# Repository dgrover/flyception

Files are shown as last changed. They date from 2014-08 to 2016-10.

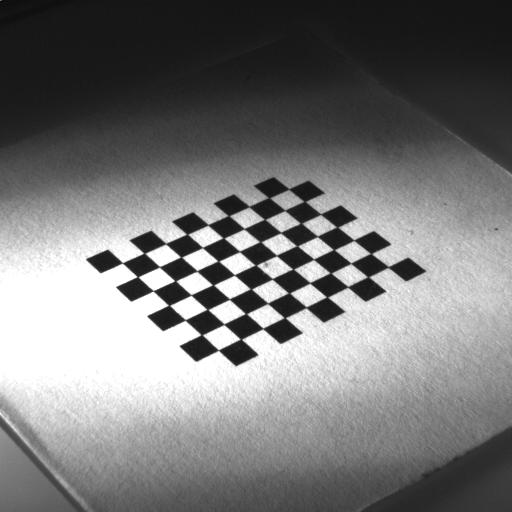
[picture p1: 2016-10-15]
calibration/arena/cbview_09192016.jpg

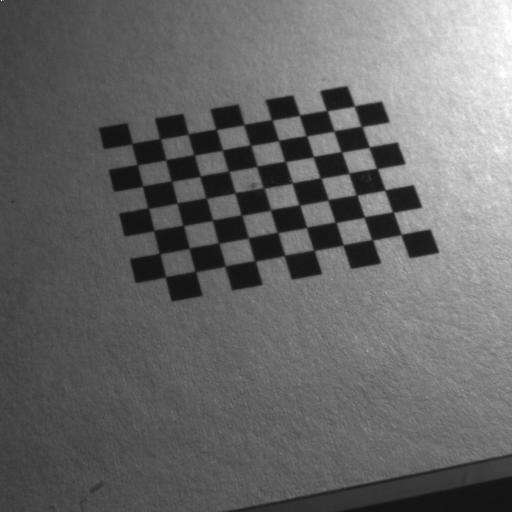
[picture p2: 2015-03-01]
calibration/arena/cbview_06192015.jpg

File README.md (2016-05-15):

# flyception

Flyception is a tracking and imaging system that enables the monitoring of brain activity in freely walking fruit flies, making the analysis of calcium dynamics possible in studies of neural mechanisms such as those that underlie social behaviors.

Please cite the following publication when used - 

Grover D, Katsuki T, Greenspan RJ. Flyception: imaging brain activity in freely walking fruit flies. Nat. Methods doi:10.1038/NMETH.3866 (2016)

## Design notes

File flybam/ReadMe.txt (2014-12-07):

========================================================================
    CONSOLE APPLICATION : flybam Project Overview
========================================================================

AppWizard has created this flybam application for you.

This file contains a summary of what you will find in each of the files that
make up your flybam application.

flybam.vcxproj
    This is the main project file for VC++ projects generated using an Application Wizard.
    It contains information about the version of Visual C++ that generated the file, and
    information about the platforms, configurations, and project features selected with the
    Application Wizard.

flybam.vcxproj.filters
    This is the filters file for VC++ projects generated using an Application Wizard. 
    It contains information about the association between the files in your project 
    and the filters. This association is used in the IDE to show grouping of files with
    similar extensions under a specific node (for e.g. ".cpp" files are associated with the
    "Source Files" filter).

flybam.cpp
    This is the main application source file.

/////////////////////////////////////////////////////////////////////////////
Other standard files:

StdAfx.h, StdAfx.cpp
    These files are used to build a precompiled header (PCH) file
    named flybam.pch and a precompiled types file named StdAfx.obj.

/////////////////////////////////////////////////////////////////////////////
Other notes:

AppWizard uses "TODO:" comments to indicate parts of the source code you
should add to or customize.

/////////////////////////////////////////////////////////////////////////////

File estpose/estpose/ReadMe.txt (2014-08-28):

========================================================================
    CONSOLE APPLICATION : estpose Project Overview
========================================================================

AppWizard has created this estpose application for you.

This file contains a summary of what you will find in each of the files that
make up your estpose application.

estpose.vcxproj
    This is the main project file for VC++ projects generated using an Application Wizard.
    It contains information about the version of Visual C++ that generated the file, and
    information about the platforms, configurations, and project features selected with the
    Application Wizard.

estpose.vcxproj.filters
    This is the filters file for VC++ projects generated using an Application Wizard. 
    It contains information about the association between the files in your project 
    and the filters. This association is used in the IDE to show grouping of files with
    similar extensions under a specific node (for e.g. ".cpp" files are associated with the
    "Source Files" filter).

estpose.cpp
    This is the main application source file.

/////////////////////////////////////////////////////////////////////////////
Other standard files:

StdAfx.h, StdAfx.cpp
    These files are used to build a precompiled header (PCH) file
    named estpose.pch and a precompiled types file named StdAfx.obj.

/////////////////////////////////////////////////////////////////////////////
Other notes:

AppWizard uses "TODO:" comments to indicate parts of the source code you
should add to or customize.

/////////////////////////////////////////////////////////////////////////////

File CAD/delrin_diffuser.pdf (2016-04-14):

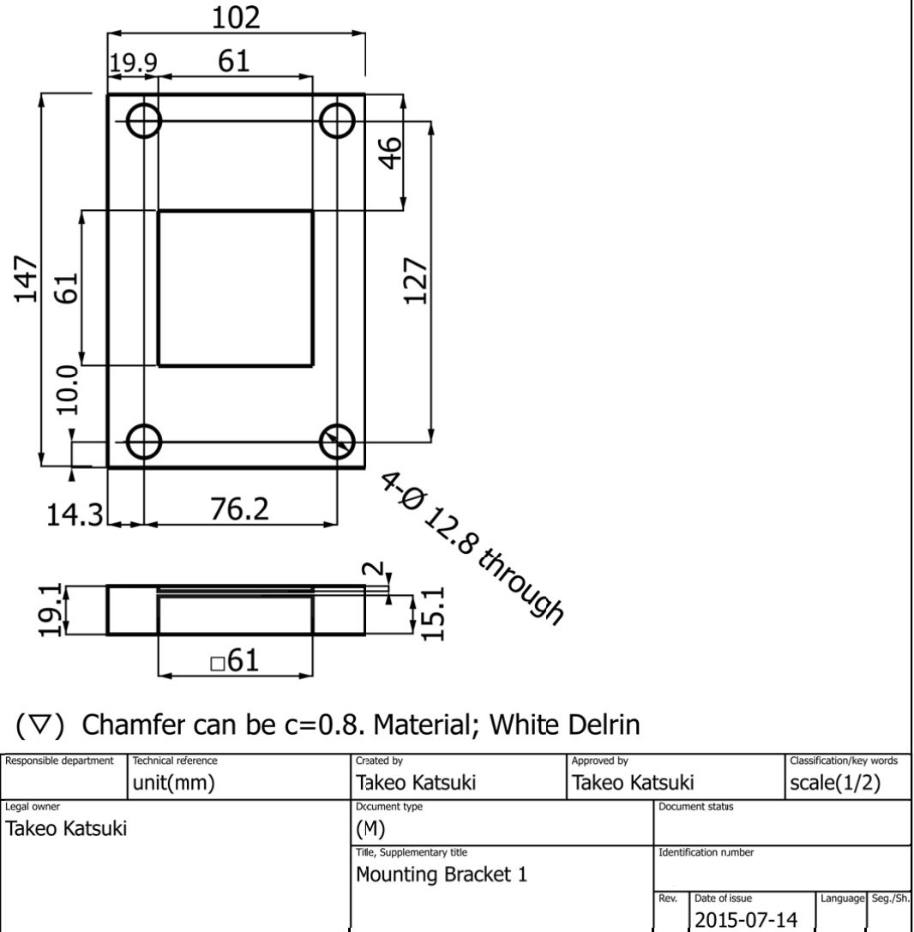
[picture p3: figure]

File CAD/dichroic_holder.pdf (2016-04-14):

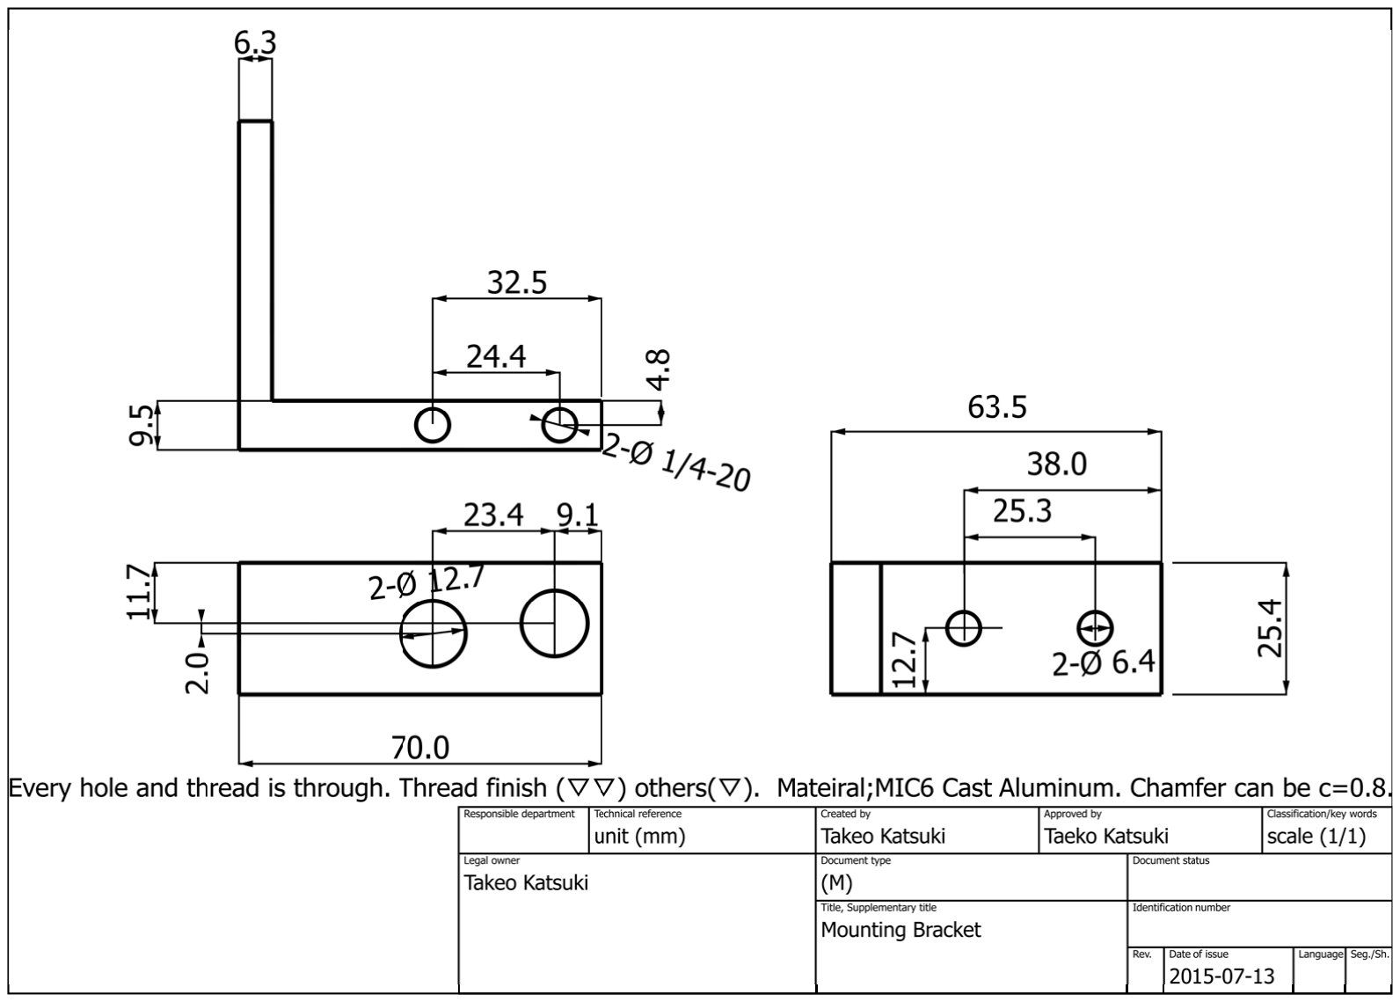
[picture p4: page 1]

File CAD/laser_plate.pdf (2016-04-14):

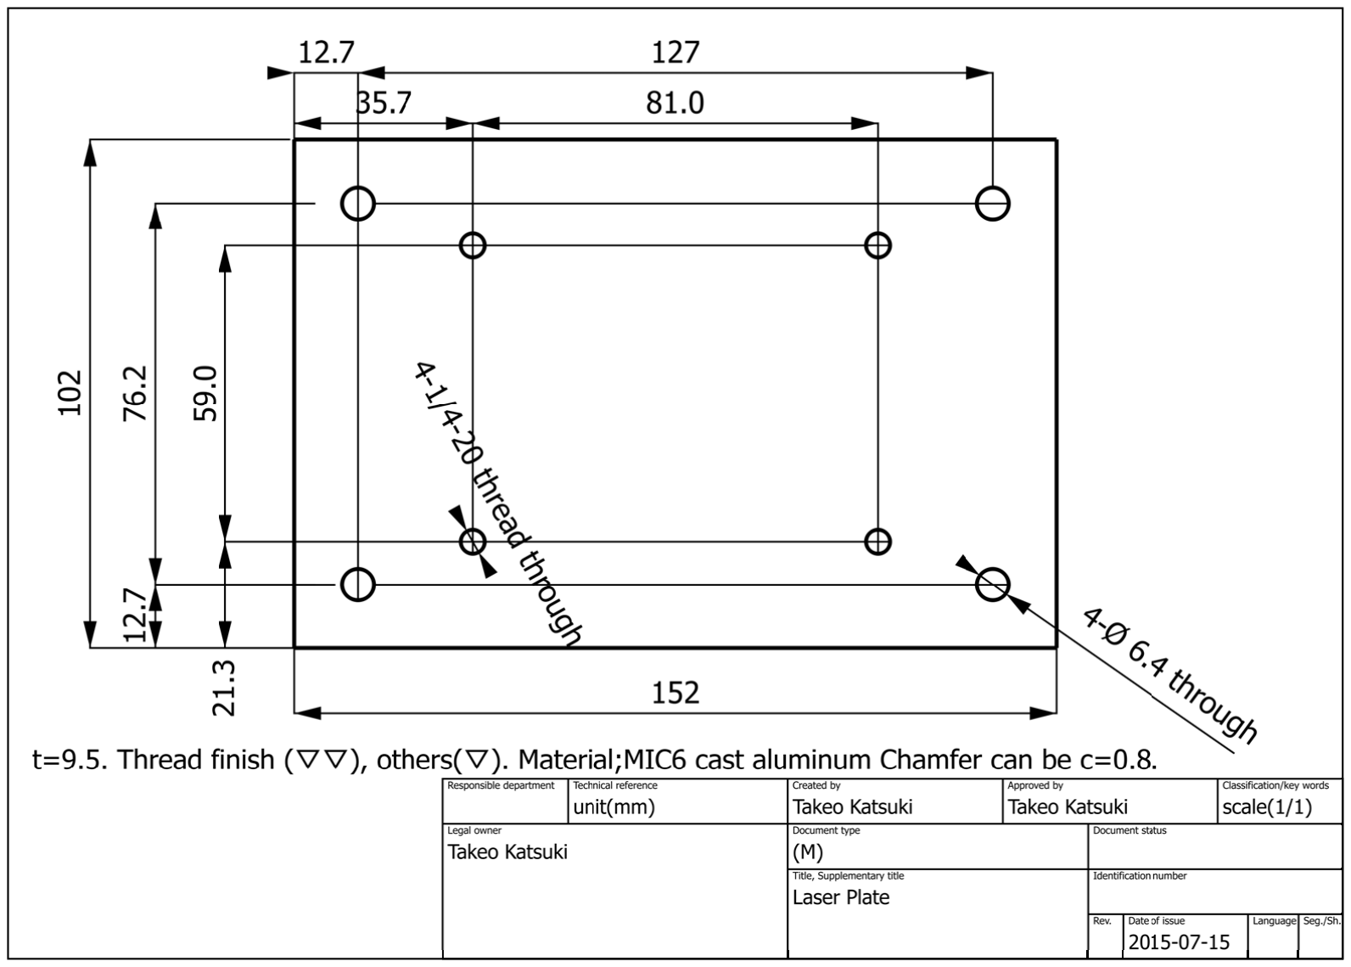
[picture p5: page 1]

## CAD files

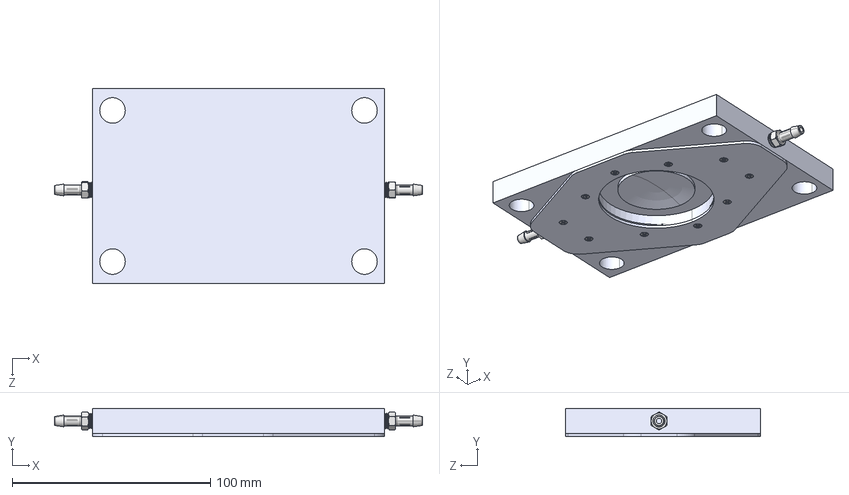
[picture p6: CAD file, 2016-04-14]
CAD/arena_fixture.STEP
185.5 x 14.3 x 98.4 mm
takeo''s fixture base
takeo''s fixture top
flat head screw_ai_CR-FHMS 0.086-64x0.3125x0.3125-N x 10
5047K114 fitting_5047K114 x 2

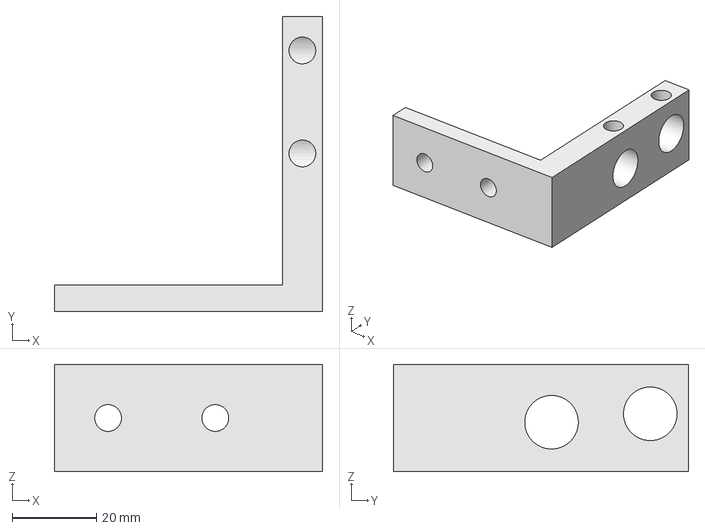
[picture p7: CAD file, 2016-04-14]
CAD/dichroic_holder.step
63.5 x 70.0 x 25.4 mm

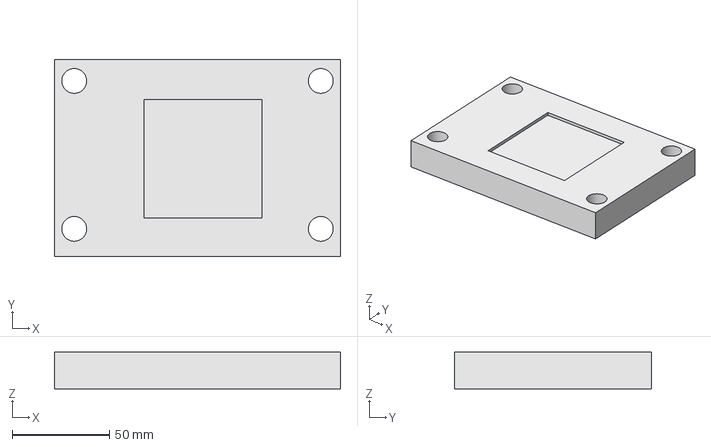
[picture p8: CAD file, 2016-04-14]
CAD/delrin_diffuser.step
147.3 x 101.6 x 19.1 mm

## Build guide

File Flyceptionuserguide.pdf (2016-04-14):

# Flyception user manual

### Dhruv Grover, Takeo Katsuki, and Ralph J. Greenspan

Version 1.0
2016-4-13

# Table of contents

Installation
Prerequisites
Hardware configuration on test setup Getting Started
Compiling
Custom building OpenCV with CMake
Compiling custom OpenCV source in Visual Studio Setting up Flyception
Compiling Flyception
Arenaview Camera Calibration
Using Flyception
Fluorescence video recording with MicroManager Postacquisition Image analysis on R

# Installation

## Prerequisites

PC running Microsoft Windows 7/8 64-bit Microsoft Visual Studio 2013 Professional Edition CMake
OpenCV library
Point Grey Flycapture SDK 64-bit
Teledyne DALSA Sapera LT SDK NI-DAQmx
Arduino
MicroManager

## Hardware configuration on test setup

Dell Precision T7610 Workstation (Sixcore 2.6GHz)
16GB RAM
2x256GB SSD drives, one for Windows OS and second for video recording Teledyne DALSA XCelera PX4 full framegrabber PCIE card

National Instruments PCIE-6351 DAQ Point Grey 2-port USB3 PCIE card Firewire 800 card
Arduino Mega 2560

## Getting Started

Download and install Microsoft Visual Studio 2013. For academic use, free licensed copies of the software are available on dreamspark.com

Download and install CMake v3.3 or above (https://cmake.org/).

Download OpenCV source code (v3.0 or above required) from GitHub (https://github.com/Itseez/opencv). OpenCV for windows provided on opencv.org can also be downloaded as it includes the source code along with a default build, however, the flyception software requires a custom build of OpenCV.

Download and install the latest version of Point Grey Flycapture SDK 64-bit (v2.8 or above) from (https://www.ptgrey.com/support/downloads).

Download and install the latest version of National Instruments DAQmx software from (http://sine.ni.com/nips/cds/view/p/lang/en/nid/10181).

Download and install the Sapera LT SDK from Teledyne DALSA (https://www.teledynedalsa.com/imaging/products/software/sapera/lt/). An account creation step might be required for software download. This software is included with the framegrabber card.

Download and install the latest Arduino IDE environment from (https://www.arduino.cc/en/Main/Software).

Download and install the latest version of MicroManager (https://www.micromanager.org/). (https://www.micro-manager.org/)

# Compiling

## Custom building OpenCV with CMake

The following instructions are similar to those provided by OpenCV at (http://docs.opencv.org/3.0-beta/doc/tutorials/introduction/windows_install/windows_install.html)

Unzip the OpenCV source code to C:\SDK\opencv-3.0.0\sources\ folder
Create a folder C:\SDK\opencv-3.0.0\build\ to hold the custom built binaries
Run the cmakegui program
Enter the full paths for the OpenCV source code and binaries
Select the grouped and advanced options and press configure
Select Visual Studio 12.0 (2013) Win64 as the compiler of choice Uncheck BUILD->DOCS
Check WITH->WITH_OPENMP
Press configure again and verify that OpenMP module has been loaded
Press configure again to include OpenMP and then press generate

The source code for the OpenCV library with OpenMP support for Visual Studio 2013 will now be saved to the binaries folder indicated in CMake.

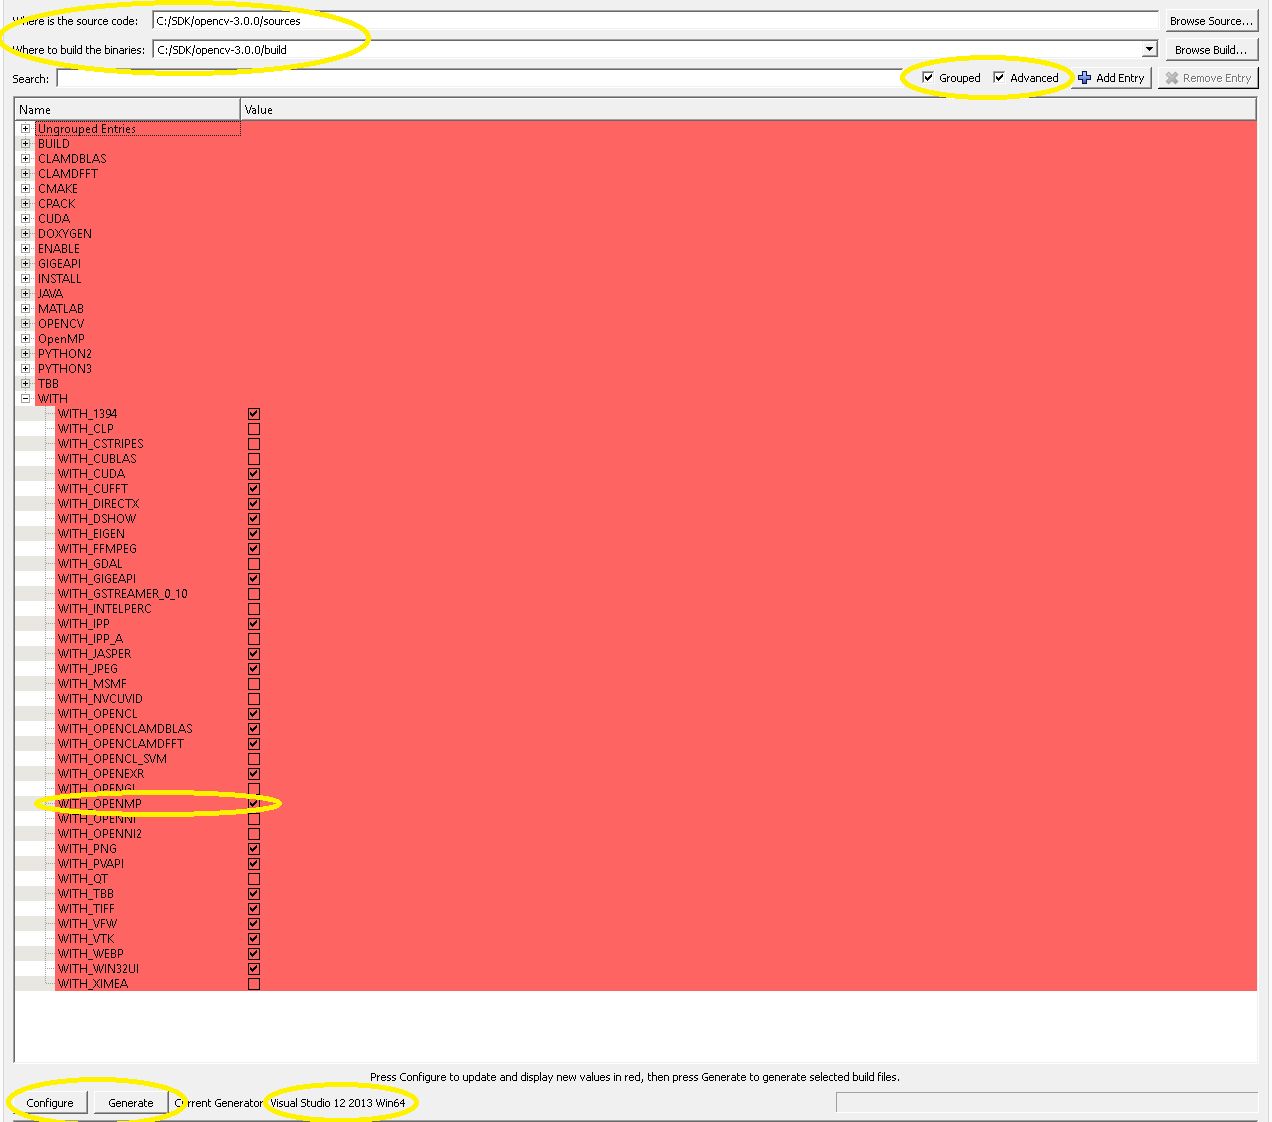
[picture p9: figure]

## Compiling custom OpenCV source in Visual Studio

Navigate to C:\SDK\opencv-3.0.0\build and run the OpenCV.sln visual studio solution file

Once loaded, select the ALL_BUILD project and use the RELEASE solution configuration, and x64 solution platform. Select the BUILD menu item and then build ALL_BUILD

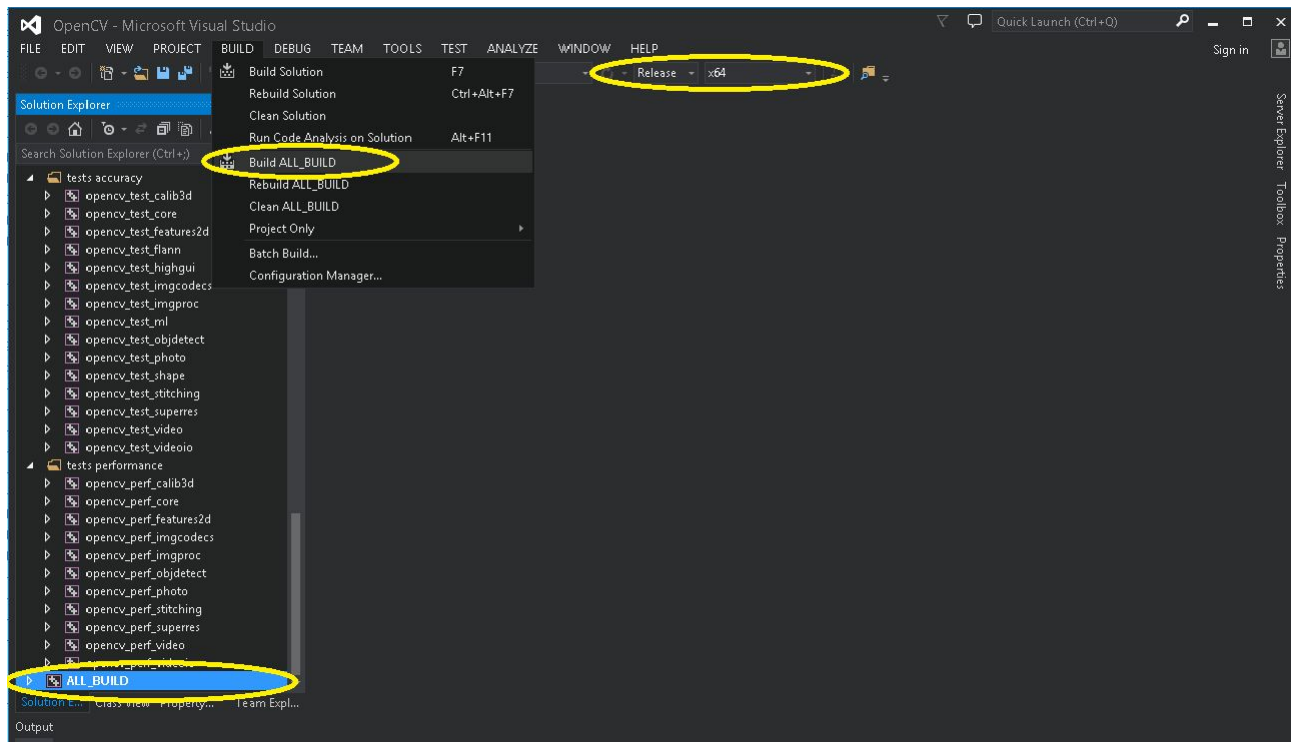
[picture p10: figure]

OpenCV should now begin compiling. This process may take a few minutes.

Once compiled, select the INSTALL project and then the BUILD menu item followed by build INSTALL. This installs the OpenCV binaries built to the folder C:\SDK\opencv-3.0.0\build\install\

Custom binaries of OpenCV with OpenMP support are now built and are saved to the following folders. In the next section, we will be including these folder paths when compiling the flyception source code

INCLUDE PATH C:\SDK\opencv-3.0.0\build\install\include
LIB PATH C:\SDK\opencv-3.0.0\build\install\x64\vc12\lib
BIN PATH C:\SDK\opencv-3.0.0\build\install\x64\vc12\bin

Note: Path to the OpenCV bin folder needs to be included in the SYSTEM Path. This can be achieved by navigating to Control Panel > System > Advanced System Settings > Environment Variables > System Variables > Path. Add the aforementioned BIN PATH to the path string. A restart of Windows may be required for the system path to be refreshed.

## Setting up Flyception

Download the latest version of the flyception source code from https://github.com/dgrover/flyception.

The flyception source code has the following folder hierarchy:
Flyception root folder
Flyception\Arduino includes code to be installed on the arduino for camera triggering and odor delivery
Flyception\flybam source code for the tracking program
Flyception\calibration scripts to calibrate the arenaview camera to convert pixel coordinates to realworld coordinates
Flyception\ccf camera link configuration file for Point Grey Gazelle camera (flyview)

Compile and upload the arduino sketch multi_cam_trigger_mega to the first arduino. This generates PWM signals to trigger the arenaview, flyview, fluoview cameras and the flash using synchronized arduino timers.

## Compiling Flyception

Navigate to the Flyception\flybam folder and run the flybam.sln solution file.
Verify that the x64\RELEASE solution platform is selected.

The provided project file includes the path to all prerequisite libraries, however, if custom folders were used, the library paths need to be changed here.

Navigate to Project > flybam properties > configuration properties > vc++ directories
Verify the following directories are included

Include directories
C:\Program Files\Point Grey Research\FlyCapture2\include C:\SDK\opencv-3.0.0\build\install\include
C:\Program Files x86\National Instruments\Shared\ExternalCompilerSupport\C\include C:\Program Files\Teledyne DALSA\Sapera\Examples\Classes\Common
C:\Program Files\Teledyne DALSA\Sapera\Classes\Basic
C:\Program Files\Teledyne DALSA\Sapera\Include

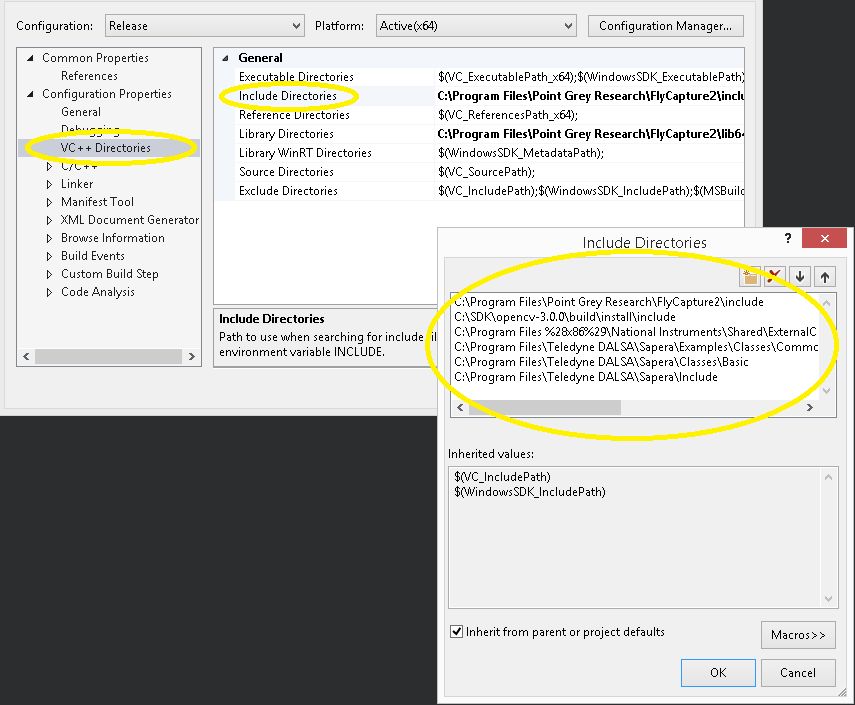
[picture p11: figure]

Library directories
C:\Program Files\Point Grey Research\FlyCapture2\lib64 C:\SDK\opencv-3.0.0\build\install\x64\vc12\lib
C:\Program Files %28x86%29\National Instruments\Shared\ExternalCompilerSupport\C\lib64\msvc C:\Program Files\Teledyne DALSA\Sapera\Lib\Win64
Under Linker > Input, verify the following .lib files are included

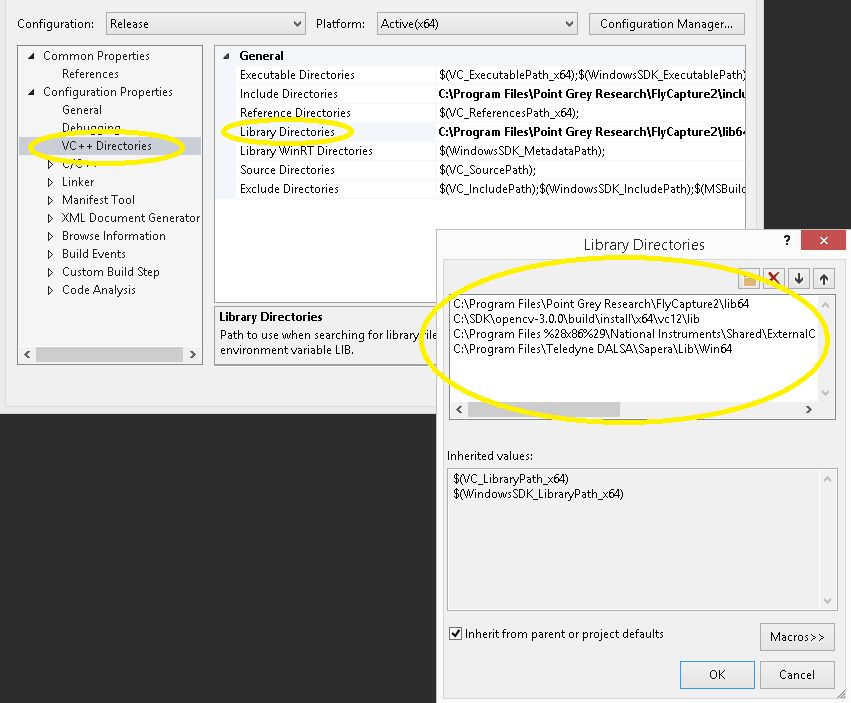
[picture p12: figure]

nid

a

q

m

x.lib
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
2.lib
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
UI.lib
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
0.lib
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
0.lib
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
0.lib
o

p

e

n

c

v_im

g

p

r

o

c

3

0

0.lib
o

p

e

n

c

v_im

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
0.lib
o

p

e

n

c

v_

c

alib

3

d

3

0

0.lib
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
sic.lib

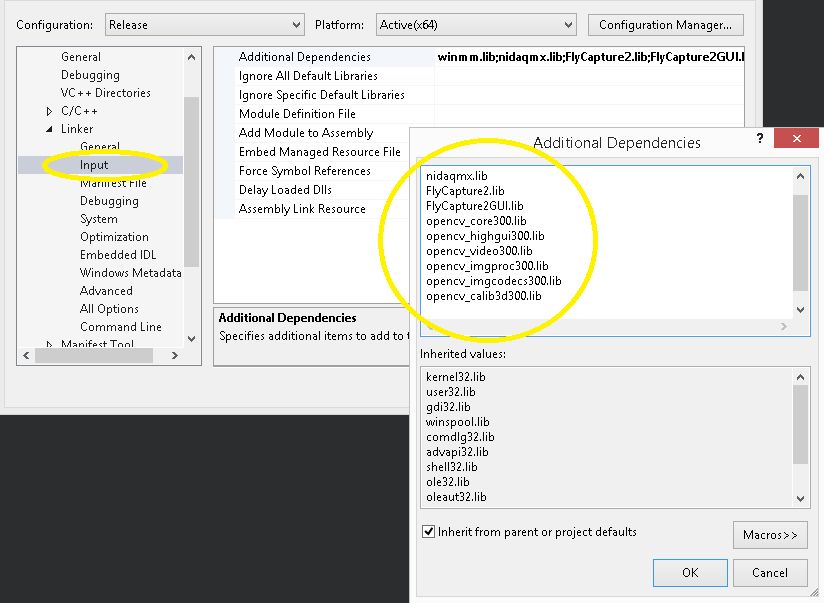
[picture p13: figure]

With these folder paths included, the flyception software is ready to be compiled and executed.

# Arenaview Camera Calibration

We follow a similar procedure to the OpenCV tutorial on camera calibration. In short, the distortion and camera matrices are calculated from arenaview input images of a checkerboard target at different orientations (roughly 8-10 images are sufficient for accurate calibration, see calibration\arena\images folder for samples). The calibration\arena\images subfolder includes images taken during a successful calibration.

See the following link for a tutorial with detailed description on the theory and use of the camera calibration routines.
(http://docs.opencv.org/3.0-beta/doc/tutorials/calib3d/camera_calibration/camera_calibration.ht ml) (http://docs.opencv.org/3.0-beta/doc/tutorials/calib3d/camera_calibration/camera_calibration.html)

The calibration\calib folder includes code which reads in the images stored in calibration\arena\images folder and outputs the camera and distortion matrices to the out_camera_data.xml file. Next, the camera projection matrix is calculated using the distortion and camera matrices and an image of the checkerboard centered in line with the center of the fly arena. This is to ensure that fly coordinates outputted by the flyception program are in mm’s with the origin being the center of the arena. See code in calibration\project folder. The code reads in the out_camera_data.xml file and outputs the camera_projection_data.xml file which is read into the main flyception program.

# Using Flyception

When the flyception code is executed, the arenaview and flycameras are initialized (see screenshot below). The software automatically starts tracking flies in the arenaview video and turns the galvanometer mirrors to follow the first fly tracked. The following keyboard shortcuts used for controlling the software

F1 initializes flyview tracking
F2 starts/stops recording of arenaview and flyview images and tracking coordinates. If the fluoview camera is initialized via MicroManager (see next section), recording of fluovidoes will also begin.
F3 fires the flash, with an additional automatic flash fired 60s later.
F4 opens pneumatic valve for odor delivery experiments.
UP, DOWN, LEFT, RIGHT keys manual control of galvanometer mirror assembly HOME switches back from manual galvanometer control mode to automatic arenaview tracking mode
ESC exits the program

In addition to the keyboard shortcuts, flyception also allows the user to tweak various tracking parameters via a control panel. For instance, thresholds for arenaview and flyview tracking, morphological operations and head offset position from the top of the fly head in flyview can be user controlled.

Other parameters such as number of flies, length of videos, arena dimensions, galvo settings can be changed in the stdafx.h file in the flybam directory. If the system is replicated exactly as outlined in this article, most of these settings need not be altered.

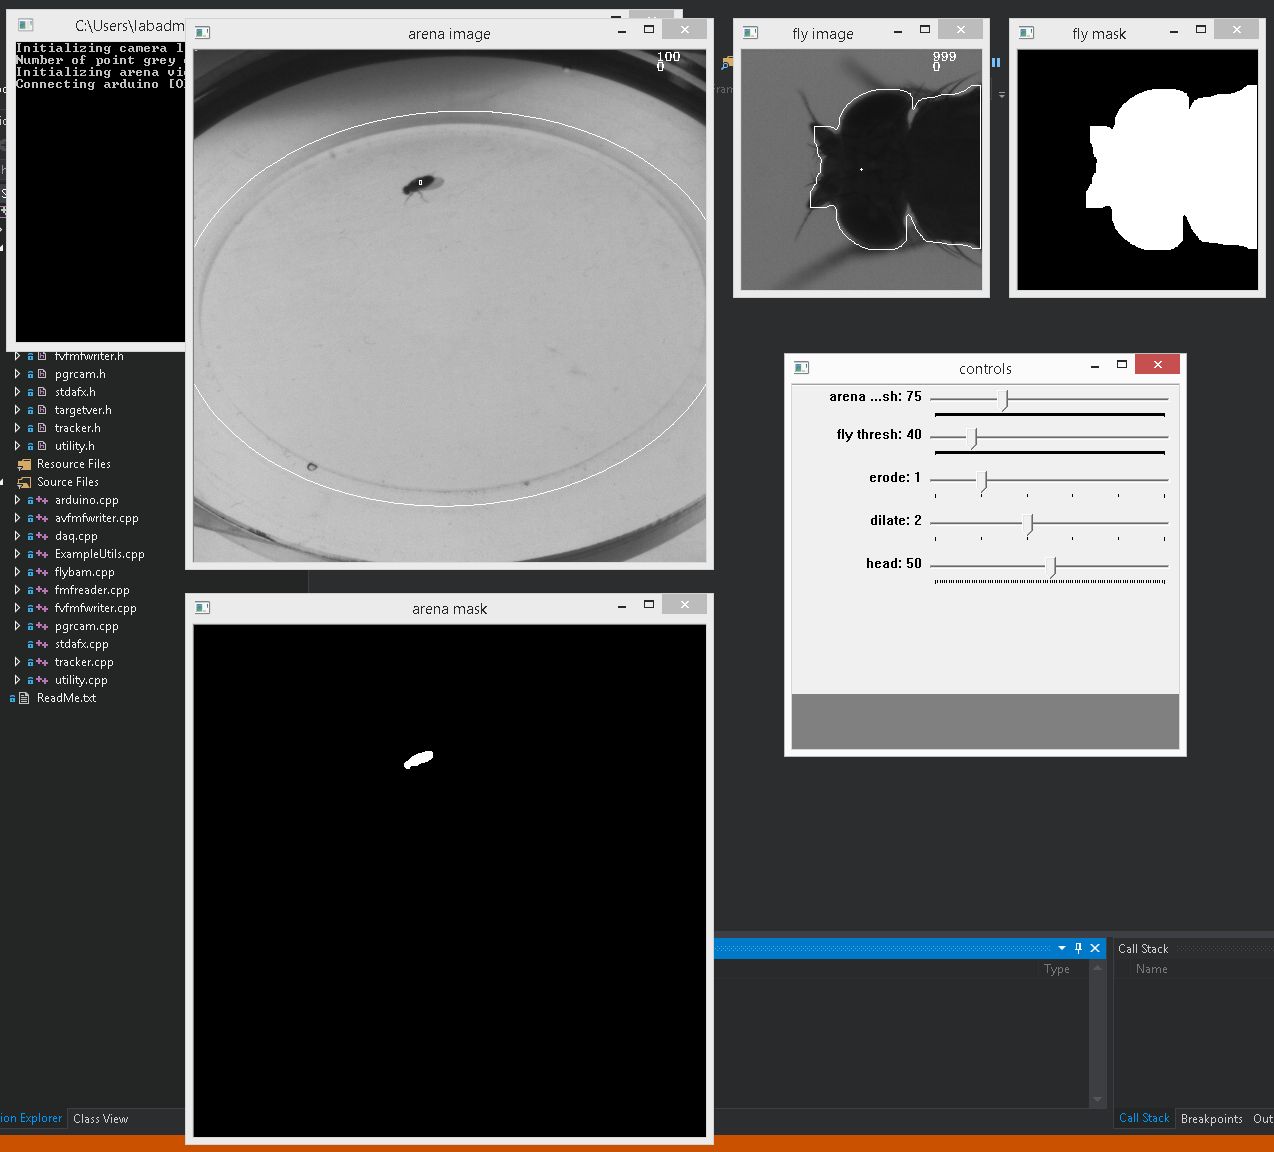
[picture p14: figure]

The output of the system after a successful recording session is as follows
Arena view video (default length 100s) in .fmf format
Flyview video (default length 100s) in .fmf format
Arena view and fly video log files to ensure cameras are functioning at preset frame rates
Trajectory file, space delimited, with the following parameters per frame at 1000Hz [Frame Number, Arena xcoordinate, Arena ycoordinate, Flyview head center xcoordinate, Flyview head center ycoordinate, Flyview body edge center xcoordinate, Flyview body edge center ycoordinate, Galvo xangle, Galvo yangle, Odor delivered (true/false)]

# Fluorescence video recording with MicroManager

Fluorescence images are captured with a Rolera EM-C2 EM-CCD camera using MicroManager. The camera settings are controlled in the Device Property Browser shown in the screen capture below with the following parameters;

Trigger Type: Strobe Hi
EM Gain: 3,500
Pixel Type: 14 bit
Readout Time: 20.0 MHz
Binning: 1 or 2

F2 key needs to be bound to multi-D acquisition function so that the image acquisition starts roughly at the same time as flyview and arenaview. Number of images to capture is set to 10,000 in Multi-D Acquisition setting. Image size is reduced to 125x125 pixels (62x62 in the case of binning 2) by pressing the ROI button.

Note that users must launch MicroManager before the flyception tracking software, and make sure to assign only one processing core instead of all cores to the java process in order to avoid resource conflicts between the tracking software and MicroManager. This can be done through Task Manager of the Windows operating system.

Start the camera by hitting Live button in the main console, and then start recording with F2 shortcut key. Images will be saved in TIFF format and metadata will be saved in TXT format, with a userspecified filename prefix.

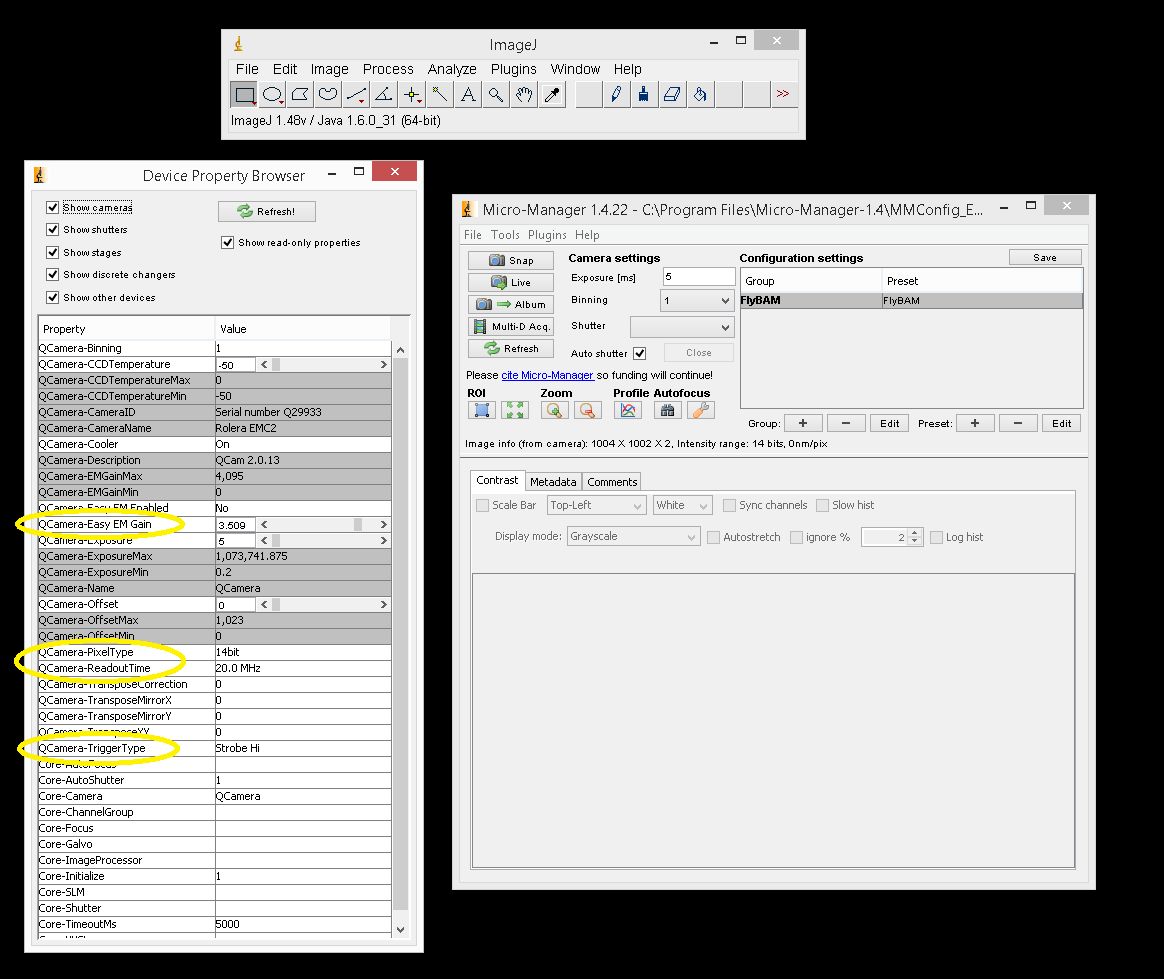
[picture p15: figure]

# Postacquisition Image analysis on R

Quantification of fluorescence changes is done using custom scripts written in R. The scripts load a flyview video and estimate a set of transformation functions that achieves nearstationary fly image via image registration. The same set of transformation is applied to fluoview image so that the fluorescence intensity can be measured with a subbrain resolution. All the image processing and analysis steps are included in one R function Flyception(), and this function outputs a total of about 60 files depending on the options chosen. Even though the analysis is highly automated, since R is an interpreted language, every step of analysis is customizable linebyline if desired.

The two fmf files, four log files, one tiff file, and one txt file generated from flyception and MicroManager need to be placed in one directory.

In addition to the scripts included in this supplementary material, following R packages are required to analyze flyception data. Follow the instruction of each package for installation. RImageBook
Rcpp
zoo
RNiftyReg
plotrix
ggplot2
plyr
reshape2
rlogging

Usage:
Flyception(rdir, dir, prefix, autopos=T, video_out=F, mating=F, stimlen=200, stimplotlen=800, reuse=T, fmf2tif=T, fpsfl=100)

Arguments:
rdir | a character vector of directory name that contains R scripts
dir | a character vector of directory name that contains video data flyception
generated
prefix | a character vector used for output file names
autopos | logical: should image alignment automatically performed using FNCC?
video_out | logical: should .mp4 videos generated?
mating | logical: analyze mating behavior?
stimlen | integer indicating the length of stimulus in a number of frames
stimplotlen | integer indicating the length of a dF/F plot and dF/F image representation
reuse | logical: should RDS files be used from the previous process?
fmf2tif | logical: should fmf files be converted to tif?
fpsfl | integer indicating the frame rate of fluoview camera

Details:
This function provides an automated pipeline for performing the following image processing steps and saves resulted images and plots in the folder specified in the dir argument. log.txt contains The main processes are alignment of flyview and fluoview videos; segmentation of the optical window on the fly head; image registration of flyview, window mask, and fluoview videos; calculation of fluorescence intensity changes with dF/F plots and dF/F heat maps; generation of fly trajectories; and generation of a number of matric such as speed of the fly, tracking error, image focus, and window size, which can be used for filtering out frames that don’t fit userdefined criteria. The function also provides options to convert FMF files into TIFF files and to generate mp4 videos for presenting results. Users can also opt to reuse RDS files generated from the first run to skip timeconsuming steps such as image registration in subsequent analyses with different parameters.

Examples:

rdir < "C:/path/to/the/directory/containing/scripts" source(paste0(rdir, "Flyception.R"))
dir < "C:/path/to/the/directory/containing/sample_data"
prefix < "OK107-Gal4_UAS-myr-EGFP_2"
Flyception(rdir=rdir, dir=dir, prefix=prefix, autopos=T, video_out=F, mating=F, stimlen=20, stimplotlen=80, reuse=T, fmf2tif=T, fpsfl=100)

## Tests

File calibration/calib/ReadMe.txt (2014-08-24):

========================================================================
    CONSOLE APPLICATION : calib Project Overview
========================================================================

AppWizard has created this calib application for you.

This file contains a summary of what you will find in each of the files that
make up your calib application.

calib.vcxproj
    This is the main project file for VC++ projects generated using an Application Wizard.
    It contains information about the version of Visual C++ that generated the file, and
    information about the platforms, configurations, and project features selected with the
    Application Wizard.

calib.vcxproj.filters
    This is the filters file for VC++ projects generated using an Application Wizard. 
    It contains information about the association between the files in your project 
    and the filters. This association is used in the IDE to show grouping of files with
    similar extensions under a specific node (for e.g. ".cpp" files are associated with the
    "Source Files" filter).

calib.cpp
    This is the main application source file.

/////////////////////////////////////////////////////////////////////////////
Other standard files:

StdAfx.h, StdAfx.cpp
    These files are used to build a precompiled header (PCH) file
    named calib.pch and a precompiled types file named StdAfx.obj.

/////////////////////////////////////////////////////////////////////////////
Other notes:

AppWizard uses "TODO:" comments to indicate parts of the source code you
should add to or customize.

/////////////////////////////////////////////////////////////////////////////

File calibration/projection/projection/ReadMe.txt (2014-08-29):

========================================================================
    CONSOLE APPLICATION : projection Project Overview
========================================================================

AppWizard has created this projection application for you.

This file contains a summary of what you will find in each of the files that
make up your projection application.

projection.vcxproj
    This is the main project file for VC++ projects generated using an Application Wizard.
    It contains information about the version of Visual C++ that generated the file, and
    information about the platforms, configurations, and project features selected with the
    Application Wizard.

projection.vcxproj.filters
    This is the filters file for VC++ projects generated using an Application Wizard. 
    It contains information about the association between the files in your project 
    and the filters. This association is used in the IDE to show grouping of files with
    similar extensions under a specific node (for e.g. ".cpp" files are associated with the
    "Source Files" filter).

projection.cpp
    This is the main application source file.

/////////////////////////////////////////////////////////////////////////////
Other standard files:

StdAfx.h, StdAfx.cpp
    These files are used to build a precompiled header (PCH) file
    named projection.pch and a precompiled types file named StdAfx.obj.

/////////////////////////////////////////////////////////////////////////////
Other notes:

AppWizard uses "TODO:" comments to indicate parts of the source code you
should add to or customize.

/////////////////////////////////////////////////////////////////////////////

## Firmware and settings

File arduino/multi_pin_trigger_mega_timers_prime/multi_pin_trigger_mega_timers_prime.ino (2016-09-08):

int incomingByte = 0;
bool flash_fired_once = false;
int flash_count = 0;

void setup()
{
 Serial.begin(9600);	// opens serial port, sets data rate to 9600 bps
  
 pinMode(4, OUTPUT);
 digitalWrite(4, HIGH); 
 
 pinMode(9, OUTPUT);  //1kHz on timer 2 - fly-view camera
 pinMode(12, OUTPUT); // 100 Hz on timer 1 - fluo-view camera
 pinMode(2, OUTPUT);  //100 Hz on timer 3 - flash and arena-view cameras
 
 GTCCR = _BV(TSM)| _BV(PSRASY)| _BV(PSRSYNC); // halt all timers
 
 TCCR2A = _BV(COM2A0) | _BV(COM2B1) | _BV(WGM21) | _BV(WGM20); // fast PWM, clear OC2A on compare
 TCCR2B = _BV(WGM22) | _BV(CS22); // fast PWM, prescaler of 64
 
 OCR2A = 249;  //1kHz
 OCR2B = 25;  //100us duty cycle
 
 TCCR1A = _BV(COM1A0) | _BV(COM1B1) | _BV(WGM11) | _BV(WGM10);
 TCCR1B = _BV(WGM13) | _BV(WGM12) | _BV(CS12);
 
 OCR1A = 624;  //100Hz 
 //OCR1A = 1249;  //50Hz  
 OCR1B = 312;  //5ms duty cycle
 //OCR1B = 500;  //8ms duty cycle
 //OCR1B = 1125;  //18ms duty cycle
 
 TCCR3A = _BV(COM3A0) | _BV(COM3B1) | _BV(WGM31) | _BV(WGM30);
 TCCR3B = _BV(WGM33) | _BV(WGM32) | _BV(CS32);
 
 OCR3A = 624;  //100Hz
 //OCR3A = 1249;  //50Hz 
 OCR3B = 6;  //100us duty cycle

 TCNT0 = 0; // set timer0 to 0
 TCNT1 = 0;  //set time 1 to 0
 TCNT2 = 0; // set timer2 to 0
 
 TCNT3H = 0; // set timer3 high byte to 0
 TCNT3L = 0; // set timer3 low byte to 0

 GTCCR = 0; // release all timers
}

void loop()
{
  if (Serial.available() > 0)
    incomingByte = Serial.read();  //if incoming flash trigger from keyboard
  
  if (incomingByte > 0)  //if there was a trigger for flash
  {
      digitalWrite(4, LOW);
      delay(1000);
      digitalWrite(4, HIGH);
      
      incomingByte = 0;
      flash_fired_once = true;
      flash_count = 0;
  }  
  
  if (flash_fired_once)
  {
    delay(10);
    flash_count++;
  }
  
  if (flash_count == 6000)
  {
      digitalWrite(4, LOW);
      delay(1000);
      digitalWrite(4, HIGH);
      
      flash_fired_once = false;
      flash_count = 0;
  }
}

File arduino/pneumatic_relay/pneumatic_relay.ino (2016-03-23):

int incomingByte = 0;   // for incoming serial data

// port 1 - 5, port 2 - 4, port 3 - 3, port 4 - 2

const int led0 = 5;  //port 1
const int led1 = 4;  //port 2

int qt = 2000;

void setup() {
        Serial.begin(9600);     // opens serial port, sets data rate to 9600 bps
        pinMode(led0,OUTPUT);
        pinMode(led1,OUTPUT);
        digitalWrite(led0,LOW);
        digitalWrite(led1,HIGH);
}
void loop() 
{
        // send data only when you receive data:
        if (Serial.available() > 0) 
        {
          // read the incoming byte:
          incomingByte = Serial.read();
                
          if( incomingByte > 48)
          {
            digitalWrite(led0,LOW);
          }
                
          if( incomingByte > 49)
          {
            digitalWrite(led0,HIGH);
            digitalWrite(led1,LOW);
            delay(qt);
            digitalWrite(led1,HIGH);
            digitalWrite(led0,LOW);
          }
        }
}

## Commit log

2014-08-01 Initial commit with basic fmf reading and two channel DAQ analog output voltage update
2014-08-02 correction to voltage conversion
2014-08-03 Added Kalman Filter, needs debugging
2014-08-04 working version of kalman filter tracking
2014-08-21 Added arena camera streaming code
2014-08-24 added working camera calibration project
2014-08-25 working towards back projection of camera points
2014-08-26 working camera calibration and projection
2014-09-01 sorting out calibration
2014-09-02 more tweaks for calibration
2014-09-16 new camera projection matrix and minor fix to projection calculation code
2014-09-29 changed name of camera class
2014-10-06 new calibration
2014-10-08 added multi-threaded display and video writing
2014-10-09 updated calibration
2014-10-22 detection of head based on wing position
2014-10-23 working multi-threaded display with controls
2014-10-30 multi-threading wing detection
2014-11-01 nested threading a no go, reverting back to omp sections working code
2014-11-02 reverting back to ellipse based calculation
    [stdafx.h]
2014-12-06 updated calibration code to opencv 3.0
2014-12-07 updated calibration methods to opencv 3.0
2014-12-07 fixed calibration code
2014-12-19 added camera triggering capability
2014-12-23 changed arduino TTL pulsing to 2ms. Fixed crashing issue with display queue.
2014-12-23 forgiveness of single frame if fly lost in fly view
    helpful when delivering a flash for camera sync.
    serial read for TTL pulse to flash
2014-12-28 added back frame rate calculation and lost frame definition
2014-12-29 ignore queued frames when program ends
2015-01-22 stops recording after 50K frames
2015-01-22 calculating frame rate from camera timestamps
2015-01-30 displaying frame rate and frames recorded on flyview image
2015-03-05 head detection based on more hull defects
2015-03-06 shutter and trigger changes due to change in tracking lens aperture size
2015-03-12 updated gain on flyview camera
2015-03-20 current working version
2015-03-21 head tracking from image pixel difference without kalman filter
2015-04-01 changed key bindings and added arduino control
    [stdafx.h]
2015-04-17 switching to 500fps for now
2015-04-18 splitting display threads by camera
2015-04-25 updated scale factor and frame rate to 570Hz
2015-05-02 running at 800hz
2015-05-04 switched from erode/dilate to open
2015-05-06 arduino pulse width triggering of imaging camera
2015-05-27 switched flyview to gazelle with sapera sdk
2015-06-02 updated arduino triggering and frame rate calculation
2015-06-12 fixed image tearing issue with more acq buffers. working version, preparing to add camera callback.
    [stdafx.h]
2015-06-12 added camera callback functionality
2015-06-20 switching to queue of sapbuffer, fixed timestamp and added frame rate plotting script
2015-06-20 switching from stl queue and critical sections to concurrent queues
2015-06-20 added frame intensity calculation for flash detection
2015-07-02 switching arena camera to callback function and overall code cleanup
2015-07-06 added saving of mirror angles, also finding fix for duplicate frames and negative head position
2015-07-18 switching to concurrency queue for streaming and writing
2015-08-14 fixed dropped frame issue with fly view camera. Also added automatic second flash firing after 3000 fluo view frames
    [stdafx.h]
2016-01-24 added odor control and arduino mega timers
2016-02-21 added user manual and camera configuration file
2016-03-23 fly merges solved by convex hull defect points
    [multi_pin_trigger_mega_timers.ino, pneumatic_relay.ino]
2016-04-14 added CAD files and user manual
    [Laser_plate.step, arena_fixture.STEP, delrin_diffuser.step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]
2016-09-08 switching to myRIO
2016-10-15 updated myRio code and minor changes to tracking
    [Prime.cfg]
2016-12-10 removed hull defect calculation for merging
2019-06-04 updated prime cfg with metadata on
    [Prime.cfg]
2019-06-21 Revert "px_volt conversion improvement and move threshold added"
    This reverts commit 0a0ad43f7953d761a64f689159277e8cf8622133.
    [stdafx.h]
2019-06-21 added better key controls for movement, fly switching and galvo homing
